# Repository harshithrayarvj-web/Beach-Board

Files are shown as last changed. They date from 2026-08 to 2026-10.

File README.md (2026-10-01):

# Beach-Board 
***Journals are separate files in the repo!***

*They contain most of the extra details*

A very dynamic and adaptable keyboard meant to pack as many punches as it can within it's relatively small form factor. Contains a raspberry pi pico, 68 hot-swapable switches, en ec11 rotary encoder, an sd card socket, and a TFT LCD, while being meant to operate on QMK.


# The idea behind it
As much as modern keyboards have numerous shortcuts and even gestures for other inputs, I felt that a centralized unit that could do almost all of those things, and more, could be very useful to quickly do things in a straight forward way, similar to a streamdeck. I plan on leveraging the keyboard layout to make it more moldable and flexible for complex tasks, even if they have many smaller details. Along with this I wanted to expand on how screens could be used on keyboards, instead of basic simple screens that show just one type of data, such as WPM, without much flavor, I wanted to have a screen that could potentially both add to the aesthetics of the keyboard, and provide a functional use depending on the task at hand. The theme of a beach themed "surf board" was because of my first long term profile picture that I drew, it helped me create an identity online, so I wanted to hint at that with my first proper project being a keyboard.

# Characteristics of keyboard
- 68 switches (epomaker creamy jade)
- TFT LCD - animations and information
- 16mb USB C Pi Pico
- Hotswap sockets
- Ortholinear
- Microsd card socket - expanding storage
- ec11 Rotary Encoder
- QMK (keyboard intended to be easily customizable and versatile)

# Schematic


# PCB (silkscreen)



# Firmware (MAINLY WIP)

Need to remake the layout due to losing the tab and being unable to use the other file, or I need to test it on the website again.
Keyboard layout needed to make Firmware development easier with the QMK configurator.

# Notes
The keyboard's case was designed with a good amount of clearance to make up for any tolerance issues, but that might lead to fitment issues, so try to use glue or filler items to help the keyboard come together cleaner. Although the large parts are made with clearance in mind, smaller parts like the screen support might have tight clearances, so don't be afraid to sand it down or cut off some extra bits of plastic if they don't fit.
Pay attention to how and where the small components solder to (resistors, capacitors, or the mcp), and make sure the solder doesn't short.
Try to keep an eye on how high the pico sits on the board to not make it hit the case or put too much stress on the pins if the pins are slightly off from spec, pushing them down too far might put stress on the attachment points for the pins on the pico.

# Reflection
Although the project is overall much simpler than what I aim to do for the future, it definitely helped me kick start PCB designing and showed me how to make a finished product (for the most part). It isn't perfect, and I knew that, especially since how rigid hardware can be could affect it's versatility and how future proof it is, meanwhile software can be improved constantly, and that's why I aimed for a mostly software centric keyboard, and looking back I think my fears are pretty exaggerated and unfounded in some areas, but my general prediction was true, and my lack of skill with designing parts for the case, mounting holes, or clearances showed a lot, however it is something I wish to improve on for future projects, and my keyboard showed me some issues I can look at for now. 

I think the main difficulty with the project that's worse than designing the hardware was rather finding the parts that were cheap but reliable to get, as some parts seemed cheap but did not have a reliable stock, or had enormous shipping fees (though I did have to compromise on a few things for that due to no other alternatives, and a large portion of cost came from shipping itself unfortunately from things like JLPCB and Aliexpress). This project has showed me where to start now with planning for parts and the overall components I could realistically use, something that's harder to be flexible with than even designing parts for a project, like designing the case around a certain screw/hot insert dimension.

There were also easy things that I really enjoyed to do, like placing down the footprints for the pcb, routing, adding silkscreen art, and designing some simple sections of the hardware (especially decoration, like the waves on the screen case), they were mostly enjoyable outside of trying to find settings or tools for a specific action, but I learned to use onshape and kicad decently now. 

Overall, this project really helped me jump into designing something functional and useful, letting me learn to use software like onshape and kicad, and create a BOM and work out issues with how realistic it would be, the experience is really valuable for future projects I plan on doing. The risks I took for this project like using a TFT LCD and a Microsd socket were confusing and scary due to the probability of missing something essential or something that would protect them, but the risk seems worth it as now I know about pull up resistors, decoupling capacitors, ground pour, and how to better go about routing and placing components to make them as clean as possible (but I won't lie, I like how my PCB looks rendered in white with the routes from the MCP, minus the large amount of small route sections visible, but I'm sure cleaner routing is better looking). Using my experience so far, I wish to make more projects and have them come into the real world, hopefully pushing them to be more and more reliable, efficient, and compact.

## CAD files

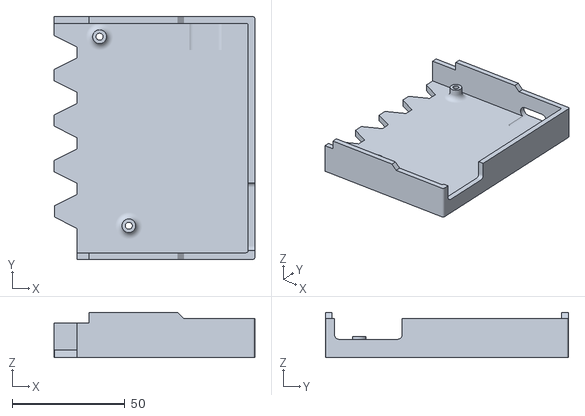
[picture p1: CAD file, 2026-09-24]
Case Base Beach-Board - Part 3.stl
89.2 x 108.0 x 20.2

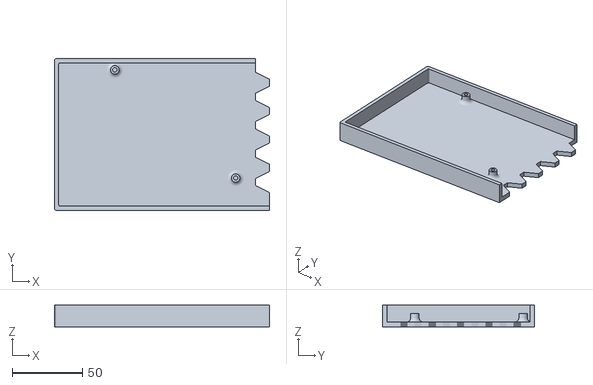
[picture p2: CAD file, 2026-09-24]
Case Base Beach-Board - Part 1.stl
153.1 x 108.0 x 15.5

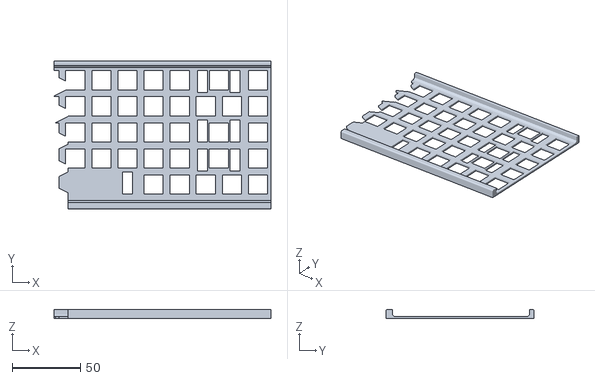
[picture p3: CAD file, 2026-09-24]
DIY Beach-Board Plate - Part 1.stl
158.5 x 108.0 x 6.50

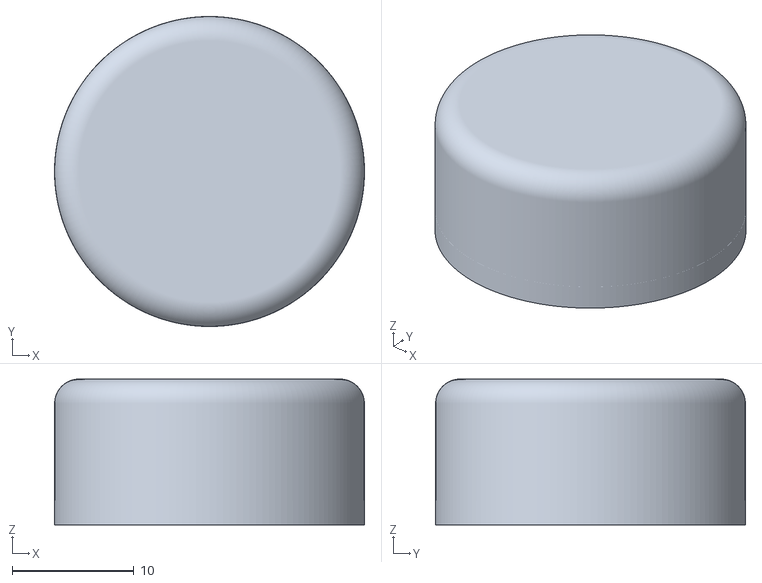
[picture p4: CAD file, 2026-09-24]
Knob Beach-Board - Part 1.stl
25.5 x 25.5 x 12.0

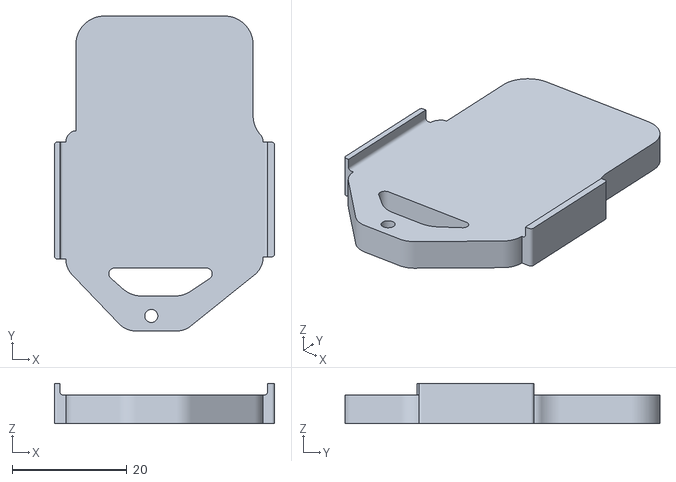
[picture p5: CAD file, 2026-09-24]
Screen Support Beach-Board - Part 1.stl
38.4 x 54.9 x 7.00

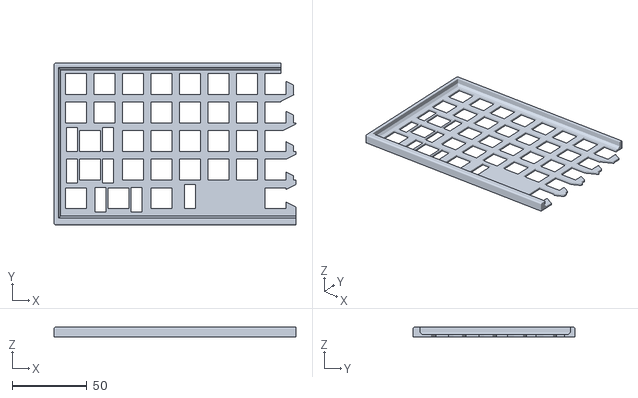
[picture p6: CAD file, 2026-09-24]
DIY Beach-Board Plate - Part 2.stl
161.5 x 108.0 x 6.50

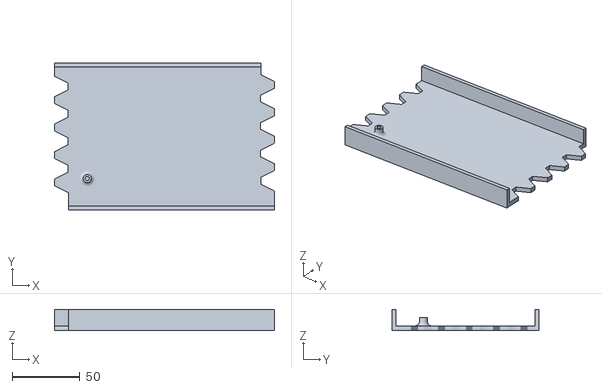
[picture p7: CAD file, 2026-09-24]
Case Base Beach-Board - Part 2.stl
162.0 x 108.0 x 15.5

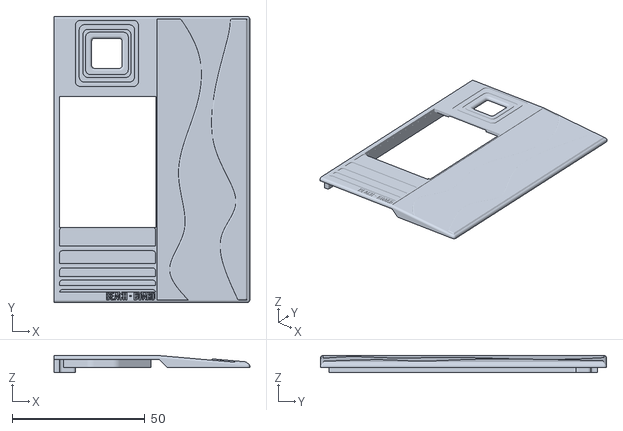
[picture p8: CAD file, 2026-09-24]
Screen area top cover Beach-Board - Part 1.stl
73.8 x 107.9 x 6.50

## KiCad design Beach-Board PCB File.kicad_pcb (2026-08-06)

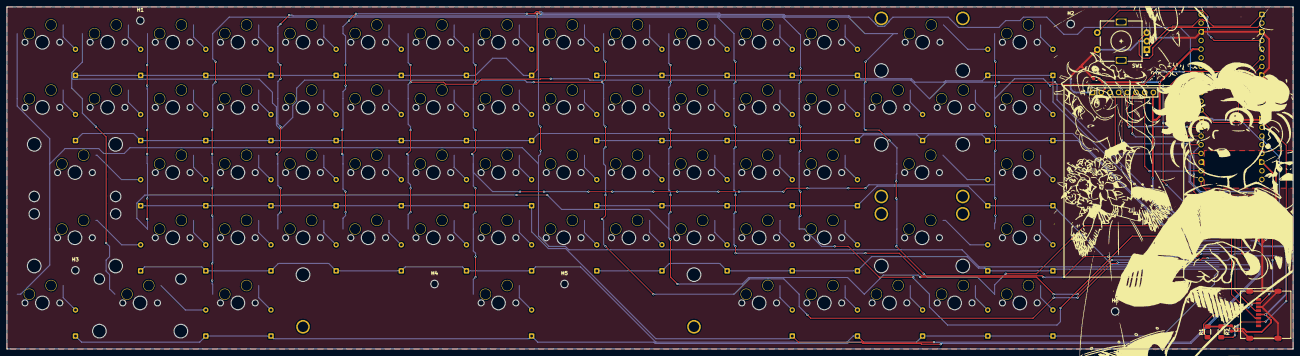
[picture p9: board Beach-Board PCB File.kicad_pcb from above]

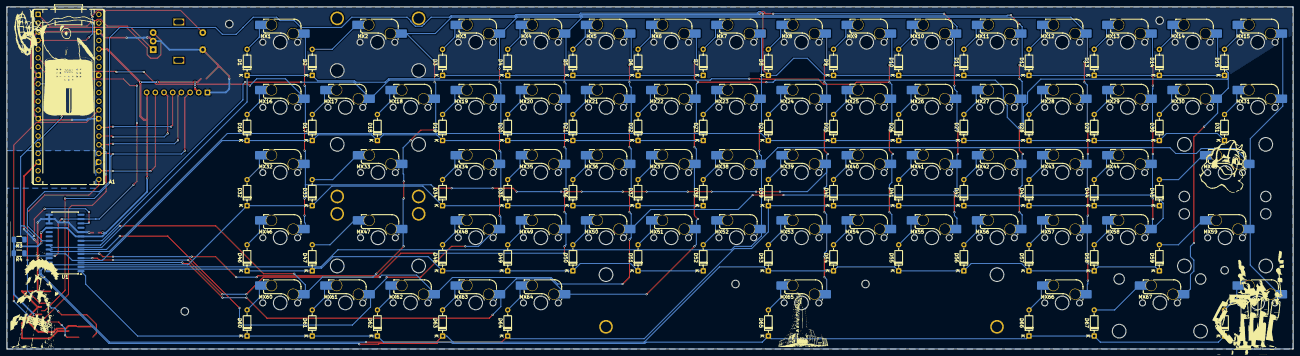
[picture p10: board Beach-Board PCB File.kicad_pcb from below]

Board: 2 copper layers, 376.0 x 100.0 mm, 161 parts (147 on the bottom side), 99 nets.

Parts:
A1: RaspberryPi_Pico; RaspberryPi_Pico_Common_THT
C1, C2, C3: 0.1uf; C_0603_1608Metric
D1, D2, D3, D4, D5, D6, D7, D8, D9, D10, D11, D12, D13, D14, D15, D16, D17, D18, D19, D20, D21, D22, D23, D24, D25, D26, D27, D28, D29, D30, D31, D32, D33, D34, D35, D36, D37, D38, D39, D40, D41, D42, D43, D44, D45, D46, D47, D48, D49, D50, D51, D52, D53, D54, D55, D56, D57, D58, D59, D60, D61, D62, D63, D64, D65, D66, D67, D68: 1N4148; D_DO-35_SOD27_P7.62mm_Horizontal
H1, H2, H3, H4, H5, H6: MountingHole; MountingHole_2.2mm_M2
J1: Conn_01x08_Pin; PinSocket_1x08_P2.54mm_Vertical
J2: Micro_SD_Card; microSD_HC_Molex_47219-2001
MX1, MX2, MX3, MX4, MX5, MX6, MX7, MX8, MX9, MX10, MX11, MX12, MX13, MX14, MX15, MX16, MX17, MX18, MX19, MX20, MX21, MX22, MX23, MX24, MX25, MX26, MX27, MX28, MX29, MX30, MX31, MX32, MX33, MX34, MX35, MX36, MX37, MX38, MX39, MX40, MX41, MX42, MX43, MX44, MX45, MX46, MX47, MX48, MX49, MX50, MX51, MX52, MX53, MX54, MX55, MX56, MX57, MX58, MX59, MX60, MX61, MX62, MX63, MX64, MX65, MX66, MX67, MX68: MX_SW_HS; SW_MX_HS_CPG151101S11_1u
R1, R2: 10K; R_1206_3216Metric_Pad1.30x1.75mm_HandSolder
R3, R4: 4.7K; R_1206_3216Metric_Pad1.30x1.75mm_HandSolder
S1, S2, S4: MX_stab; STAB_MX_P_2u
S3, S5, S7: MX_stab; STAB_MX_2u
S6: MX_stab; STAB_MX_P_7u
SW1: RotaryEncoder_Switch; RotaryEncoder_Alps_EC11E-Switch_Vertical_H20mm
U1: MCP23017x-x-SO; SOIC-28W_7.5x17.9mm_P1.27mm

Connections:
/3V3: A1.36 (3V3), C1.1, C2.1, C3.1, J1.2, J1.8, J2.4 (VDD), R1.2, R2.1, R3.2, R4.2, U1.9 (V_{DD}), U1.18 (~RESET)
/CD/DAT3: A1.29 (GPIO22), J2.2 (DAT3/CD), R2.2
/CLK: A1.24 (GPIO18), J1.3, J2.5 (CLK)
/CMD: A1.25 (GPIO19), J1.4, J2.3 (CMD)
/CS: A1.22 (GPIO17), J1.7
/Column_0: MX7.1, MX15.1, MX23.1, MX31.1, MX38.1, MX45.1, MX52.1, MX59.1, MX68.1, U1.2 (GPB1)
/Column_1: MX6.1, MX14.1, MX22.1, MX30.1, MX37.1, MX51.1, MX63.1, MX64.1, MX67.1, U1.3 (GPB2)
/Column_2: MX5.1, MX13.1, MX21.1, MX29.1, MX36.1, MX44.1, MX50.1, MX58.1, MX62.1, U1.4 (GPB3)
/Column_3: MX4.1, MX12.1, MX20.1, MX28.1, MX35.1, MX43.1, MX49.1, MX57.1, MX66.1, U1.5 (GPB4)
/Column_4: MX3.1, MX11.1, MX19.1, MX27.1, MX34.1, MX42.1, MX48.1, MX56.1, MX61.1, U1.6 (GPB5)
/Column_5: MX2.1, MX10.1, MX18.1, MX26.1, MX33.1, MX41.1, MX47.1, MX55.1, MX60.1, U1.7 (GPB6)
/Column_6: MX9.1, MX17.1, MX25.1, MX40.1, MX54.1, U1.8 (GPB7)
/Column_7: A1.9 (GPIO6), MX1.1, MX8.1, MX16.1, MX24.1, MX32.1, MX39.1, MX46.1, MX53.1, MX65.1
/DAT0: A1.21 (GPIO16), J2.7 (DAT0), R1.1
/D/C: A1.26 (GPIO20), J1.6
/RST: A1.27 (GPIO21), J1.5
/Rot-pin_A: A1.1 (GPIO0), SW1.A
/Rot-pin_B: A1.2 (GPIO1), SW1.B
/Rot-pin_S1: A1.4 (GPIO2), SW1.S1
/Row_0: D8.1 (K), D9.1 (K), D10.1 (K), D11.1 (K), D12.1 (K), D13.1 (K), D14.1 (K), D15.1 (K), U1.21 (GPA0)
/Row_1: D1.1 (K), D2.1 (K), D3.1 (K), D4.1 (K), D5.1 (K), D6.1 (K), D7.1 (K), U1.22 (GPA1)
/Row_2: D24.1 (K), D25.1 (K), D26.1 (K), D27.1 (K), D28.1 (K), D29.1 (K), D30.1 (K), D31.1 (K), U1.23 (GPA2)
/Row_3: D16.1 (K), D17.1 (K), D18.1 (K), D19.1 (K), D20.1 (K), D21.1 (K), D22.1 (K), D23.1 (K), U1.24 (GPA3)
/Row_4: D39.1 (K), D40.1 (K), D41.1 (K), D42.1 (K), D43.1 (K), D44.1 (K), D45.1 (K), D64.1 (K), U1.25 (GPA4)
/Row_5: D32.1 (K), D33.1 (K), D34.1 (K), D35.1 (K), D36.1 (K), D37.1 (K), D38.1 (K), U1.26 (GPA5)
/Row_6: D53.1 (K), D54.1 (K), D55.1 (K), D56.1 (K), D57.1 (K), D58.1 (K), D59.1 (K), D63.1 (K), U1.27 (GPA6)
/Row_7: D46.1 (K), D47.1 (K), D48.1 (K), D49.1 (K), D50.1 (K), D51.1 (K), D52.1 (K), U1.28 (GPA7)
/Row_8: D60.1 (K), D61.1 (K), D62.1 (K), D65.1 (K), D66.1 (K), D67.1 (K), D68.1 (K), U1.1 (GPB0)
/SCK: A1.7 (GPIO5), R3.1, U1.12 (SCK)
/SDA: A1.6 (GPIO4), R4.1, U1.13 (SDA)
GND: A1.3 (GND), A1.8 (GND), A1.13 (GND), A1.18 (GND), A1.23 (GND), A1.28 (GND), A1.38 (GND), C1.2, C2.2, C3.2, J1.1, J2.6 (VSS), J2.SH (SHIELD), SW1.C, SW1.S2, U1.10 (V_{SS}), U1.15 (A0), U1.16 (A1), U1.17 (A2)
unnamed: D1.2 (A), MX1.2
unnamed: D2.2 (A), MX2.2
unnamed: D3.2 (A), MX3.2
unnamed: D4.2 (A), MX4.2
unnamed: D5.2 (A), MX5.2
unnamed: D6.2 (A), MX6.2
unnamed: D7.2 (A), MX7.2
unnamed: D8.2 (A), MX8.2
unnamed: D9.2 (A), MX9.2
unnamed: D10.2 (A), MX10.2
unnamed: D11.2 (A), MX11.2
unnamed: D12.2 (A), MX12.2
unnamed: D13.2 (A), MX13.2
unnamed: D14.2 (A), MX14.2
unnamed: D15.2 (A), MX15.2
unnamed: D16.2 (A), MX16.2
unnamed: D17.2 (A), MX17.2
unnamed: D18.2 (A), MX18.2
unnamed: D19.2 (A), MX19.2
unnamed: D20.2 (A), MX20.2
unnamed: D21.2 (A), MX21.2
unnamed: D22.2 (A), MX22.2
unnamed: D23.2 (A), MX23.2
unnamed: D24.2 (A), MX24.2
unnamed: D25.2 (A), MX25.2
unnamed: D26.2 (A), MX26.2
unnamed: D27.2 (A), MX27.2
unnamed: D28.2 (A), MX28.2
unnamed: D29.2 (A), MX29.2
unnamed: D30.2 (A), MX30.2
unnamed: D31.2 (A), MX31.2
unnamed: D32.2 (A), MX32.2
unnamed: D33.2 (A), MX33.2
unnamed: D34.2 (A), MX34.2
unnamed: D35.2 (A), MX35.2
unnamed: D36.2 (A), MX36.2
unnamed: D37.2 (A), MX37.2
unnamed: D38.2 (A), MX38.2
unnamed: D39.2 (A), MX39.2
unnamed: D40.2 (A), MX40.2
unnamed: D41.2 (A), MX41.2
unnamed: D42.2 (A), MX42.2
unnamed: D43.2 (A), MX43.2
unnamed: D44.2 (A), MX44.2
unnamed: D45.2 (A), MX45.2
unnamed: D46.2 (A), MX46.2
unnamed: D47.2 (A), MX47.2
unnamed: D48.2 (A), MX48.2
unnamed: D49.2 (A), MX49.2
unnamed: D50.2 (A), MX50.2
unnamed: D51.2 (A), MX51.2
unnamed: D52.2 (A), MX52.2
unnamed: D53.2 (A), MX53.2
unnamed: D54.2 (A), MX54.2
unnamed: D55.2 (A), MX55.2
unnamed: D56.2 (A), MX56.2
unnamed: D57.2 (A), MX57.2
unnamed: D58.2 (A), MX58.2
unnamed: D59.2 (A), MX59.2
unnamed: D60.2 (A), MX60.2
unnamed: D61.2 (A), MX61.2
unnamed: D62.2 (A), MX62.2
unnamed: D63.2 (A), MX63.2
unnamed: D64.2 (A), MX64.2
unnamed: D65.2 (A), MX65.2
unnamed: D66.2 (A), MX66.2
unnamed: D67.2 (A), MX67.2
unnamed: D68.2 (A), MX68.2

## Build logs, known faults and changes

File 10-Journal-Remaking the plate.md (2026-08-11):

# *Remaking the plate*

# *Replacing the generated plate with one that was made with the svg of the front courtyard layer (8/10/2026)*- (1 Hour & 25 Minutes)
I changed the generated plate that I used before with one that was an extrusion of a sketch I made with the svg of the front courtyard layer on my pcb, and extra lines to create the walls.
I did this because I wasn't sure if generated plates were allowed, so I decided not to risk it and also took the chance to add larger holes for the stabilizers to be on the safer side.
I also made the walls thicker in general on the plate, but made them especially thick near the bottom row since it would face the most stress from my palms.






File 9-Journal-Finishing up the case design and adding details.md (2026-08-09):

# *Finishing the case design*

## *Adding walls to the plate and designs to the screen cover (8/8/2026)* - (5 Hours)
I decided to go back to the screen cover and change it's design to not make the keyboard's side feel empty, and I made it slope down off the side and also add designs to make it more beach related.
The screen cover has rounded rectangles to make it look vaporware and to extend the screen opening and fill the space below it, and the side has wave like designs to help fill that large area
while not popping out too much to be uncomfortable. I also added walls to the plate instead of adding something to clamp down on the plate like on a sandwich mount or gasket mount. I made spots for adding heatset inserts
however I need to make sure the design works tomorrow with the screws I plan on buying. In the end I decided to order most of the parts I need for the keyboard from digikey because they readily have the mcp23017
and micro sd socket I need, but they had a shipping fee so I ended up getting all the parts I need from there to make up for the shipping fee (but they also have a tarrif cost of around 3 dollars for my diodes),
outside of the screen and rotary encoder, which I'll get from aliexpress.







My final design so far:




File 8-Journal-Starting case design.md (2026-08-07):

# *Designing the models for the keyboard*

## *Importing parts and making a screen support (8/6/2026)* - (5 Hours)
I imported model into onshape, but the PCB didn't import cleanly and it lagged onshape, so I only selected parts for one key (diode and hotswap) and also the pico and mcp.
I also imported an mx switch model, stabilizer models, and 2 models for my 1.8 inch screen (so I could compare them, they had the same dimensions but different sized mounting holes).
During this stage I put the stabilizers where they should be, and also moved switches to them to check if they lined up, I found out that my stabilizers were placed rotated 180 and was thankfully
not a mounting hole problem. Placing the switches and stabilizers verified the plate that was generated by a plate generator, which I had to spend around 30 minutes to an hour to create my same keyboard digitally for it.
After I finished verifying the plate, I made the 1.8inch screen support which held onto a single mounting hole as I didn't want to risk making it hold onto another hole above, especially as the space available
wasn't enough to be confident in a 3D print (I've had a few bad experiences with a 3D printer at my public library, but I ended up going with somewhat tight models because I thought I could
trust the printing legion).
The reason why I chose a support instead of mounting holes was because I wasn't sure about where the holes would fit, and I wanted to prioritize where ethe pins were placed more than the mounting points.









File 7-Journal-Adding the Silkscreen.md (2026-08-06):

# *Adding the Silkscreen*

## *Adding the silkscreen* (8/4/2026 - 8/5/2026) (10 Hours)
Now I moved on to designing the silkscreen, and by far this took me the longest out of all the steps, with around 10 hours.
It sure took me a long time, but I ended up going with the initial test design that I used to check how it looked in white and black on jlcpcb.
I made 2 different designs but they weren't cohesive with the cover art for the TOH comic book, and I've still got a long way to go with art, so I just decided to keep it minimalist and clean.








The final silkscreen:



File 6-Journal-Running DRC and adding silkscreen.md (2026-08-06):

# *Running DRC and fixing errors*

## *Fixing errors shown by the DRC* (8/4/2026) - (2H)
At this stage I've finished checking on my schematic and finalized my routing. I've only had to exclude the antenna area for the pi pico because drc gave me an error, but the routing and ground fill were smooth.
I flipped some stabilizer footprints after DRC warned me and also cleaned up everything.




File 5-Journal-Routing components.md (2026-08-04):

# ** Checking components and final routing **

## **  Final component checks, routing components, and adding ground fill! - 8/3/2026 ** (3 Hours)
This was the final check I did on the components to make sure everything was connected properly in the schematic, and also found out that I needed 2 more resistors and a capacitor,
so I slightly tweaked the routing near the micro sd socket to accommodate for them. I also widened the 3V3 net routes since they are supposed to feed the components power.








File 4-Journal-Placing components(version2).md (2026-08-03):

# **Placing the new components on the PCB and routing them**

## **Placing the components and routing them to the pi pico - 8/2/2026 (6 Hours & 15 Minutes)
After I modified the schematic and rearanged the parts, I started on routing all the connections.
Here I had the issue of not being able to cleanly route wires due to my matrix layout and the mcp component, which ended up making me use a lot of vias.
I also reduced the size of the board after routing the pins on the pico that were close to the usb port so a usb cable could easily connect to the raspberry pi pico.
Later I would have to route the capacitors and the pull up resistors (after I change from a SMD footprint resistor) for the mcp and the microsd socket. 
Majority of the time spent was on doublechecking the parts I could get and moving parts around on the pcb to make things cleaner.













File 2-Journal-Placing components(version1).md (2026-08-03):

# **2. Placing the components for the pcb**

## **Placing the components to handle footprints and fixing the flipped issue** - 8/2/2026 (4 Hours & 30 Minutes)
After finishing the schematic, I worked on placing the components to get a general scope on where I would place the Raspberry pi pico to make the pcb be as clean and compact as it can.
I placed all the hotswap sockets but didn't realize they actually went on the back of the keyboard, so I checked the part I was going to use (Kailh hotswap socket) and verified, but it made the keyboard layout be mirrored left to right. In the end, I decided that the amount of pins available wasn't going to be enough and that the schematic had to be redone for the new matrix I needed and the different parts I wanted to use.






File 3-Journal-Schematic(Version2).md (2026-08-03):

# **3. Updating the keyboard matrix and adding a few parts**

## **Updating the Matrix and Raspberry pi pico pin connections - 8/2/2026** (4 Hours)

This session was to remake the keyboard matrix and figure out the extra parts I planned on using. I used a new matrix that had 8 rows and 9 columns to reduce the pin usage down to 17 pins
while previously the matrix used 21 pins. I had a hard time figuring out how I would connect and figure out the footprint for the display I plan on using
(changing from an oled 0.91 inch display to an 8 pin ST7735 1.8inch TFT LCD display to better suit my end goal needs), but it ended up sparing a lot of pico pins. 
I also found the microSD card reader I wanted to use to store and load data into the pico.





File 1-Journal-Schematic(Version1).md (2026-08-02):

# **1. Creating the schematic for the BeachBoard**

## **Creating the matrix for the keys - 8/1/2026** (4 Hours & 45 Minutes spent)
Today I finalized my keyboard's design and started working on the pcb's schematic!
My keyboard design uses an ortholinear layout, requiring every key to be in line (atleast if they are the same U size as another key above or below it), this made creating the matrix easier to track and create.
The parts that caused the most friction during this stage was figuring out if the hotswap sockets also included a footprint for the switch, while also figuring out the footprints for the oled, rotary encoder, and mounting holes.
Learning about the rotary encoder having a switch function also made me rethink the function of a special select key into something that functions as a mode swapper 
(but I still need to finalize on what I want that key to do exactly)







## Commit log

2026-08-04 Create 5-Journal-Running DRC and adding silkscreen.md
2026-08-06 Update and rename 5-Journal-Running DRC and adding silkscreen.md to 6-Journal-Running DRC and adding silkscreen.md
2026-08-06 Create 7-Journal-Adding the Silkscreen.md
2026-08-06 Add files via upload
    PCB files
    [Beach-Board PCB File-B_Cu.gbr, Beach-Board PCB File-B_Mask.gbr, Beach-Board PCB File-B_Paste.gbr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]
2026-08-07 Create 8-Journal-Starting case design.md
2026-08-09 Create 9-Journal-Finishing up the case design and adding details.md
2026-08-11 Create 10-Journal-Remaking the plate
2026-08-11 Update and rename 10-Journal-Remaking the plate to 10-Journal-Remaking the plate.md
2026-09-24 Added 3D printing part files
    3D printing parts I plan on printing for the keyboard
    [Case Base Beach-Board - Part 1.stl, Case Base Beach-Board - Part 2.stl, Case Base Beach-Board - Part 3.stl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]
2026-10-16 Added Beach board BOM (again)
    somehow my first bom upload didn't go through I guess, so I'm reuploading it
